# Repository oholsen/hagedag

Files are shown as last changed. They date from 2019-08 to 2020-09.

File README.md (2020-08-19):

# hagedag
DIY lawn mower robot

## Testing

Run unit tests:

    poetry run pytest -s

Run simulation:

    poetry run python .\record.py

(Replay log file, should add fail safe detection ++):

    poetry run python .\record.py .\data\burned-motor.log

## TODO

* motor burned (one wheel was tangled in grass):
  * wifi connection delayed - commands and feedback
  * figure out why robot estimate wrongly turned and why it did not recover when moving "right"
  * fix: move control to robot, detect connection delays, ignore delayed information, timestamp from STM32, use timestamp from GPS

* high load on motor detection - possibly integrate and average
  * cut in STM or in control? Control, as will get to know what is going on?
  * STM will stop robot if communication errors, safe to cut in control.
  * different max for instantaneous and average load?
  * Simply stop when above threshold (instantaneous)

* robot stuck detection: anomaly on prediction and GPS
  * measure distance travelled over last 5 say on GPS and compare to integrated speed

* wifi delay detection
    * shorter timeout (1s/2s)
    * embed timeout in command
    * alert in GUI

* stop cutter outside fence?
* cutter stuck detection
* revs sensor on cutter

* slow down near fence
* keep estimating position with odometer only when no GPS fix -> higher uncertainty

* Fence
    * increase area behind garage
    * reduce fence area near stairs

* App robustness
    * restart GPS service when USB unavailable, also ntrip client fails badly? restart service should be ok...
    * properly stop all tasks, also controld connection, from PC app
    * program firmware with heartbeat on commands

Usability:
    * Don't make PC app always be on top: run GUI task in own thread?
    * PC/Web/mobile app framework: pyplot, JS, plotly-dash, ...
    * identify what goes wrong / status
    * restart e.g. line scan from current position?

* Tidy up app:
   * remove unused code

* move app to robot

* change direction of robot

* slow down near fence, speed up in the middle (may make crash prediction below unnecessary - if reducing heartbeat timeout in robot)
* keep going for large HDOP if far from fence
* use GPS hdop in tracking, figure out why HDOP is 0.5 when RTK
* looser cut-off on no RTK - either adjust error in GPS tracking (check out HDOP in RMC)
 - or - accept no GPS for a while - at least if heading is good and is not going to crash.
 estimate time to impact from last good RTK position?
BUT: also quicker than 5s heartbeat timeout, i.e. direct STOP command if about to crash and loose RTK 
* avoid going in circles on drifting GPS: HDOP -> tracker could solve that
* area filling - scan lines
* if HDOP high: alternative targets or wait for ok HDOP
* fence bump control: reverse out from fence

* automatic charging
* docking garage
* camera
* camera coverage of garden
* realsense - mapping, collision avoidance

Mission control dashboard
- map (draw AOI, speeds/behavior, move fence, path, density, ..., GPS/tracking error, heading error)
- system health: show currents, battery level
- (E)stop button
- Duration, Ah drawn (total, trip (since charge), button for reset trip charge), distance covered
- Mode: fence bump, lines, manual, manual override (temporarily)
- Manual controls
- Start mission - which mission
- app to monitor status, with notifications on issues

Analytics
- GPS/tracking precision
- Coverage
- Replay/show mission on map

Mapping
- find fence - show position on map with manual control - recorder mode....

Mission control
- run to area of "little" probability
- speed and cut speed as fn(x,y)
- avoid tail swinging out (reverse back out, put GPS above cutter and turn around cutter)
- estimate error based on odometry and GPS signal - keep on going if looses RTK
- TODO: check GPS error when stopped and no RTK

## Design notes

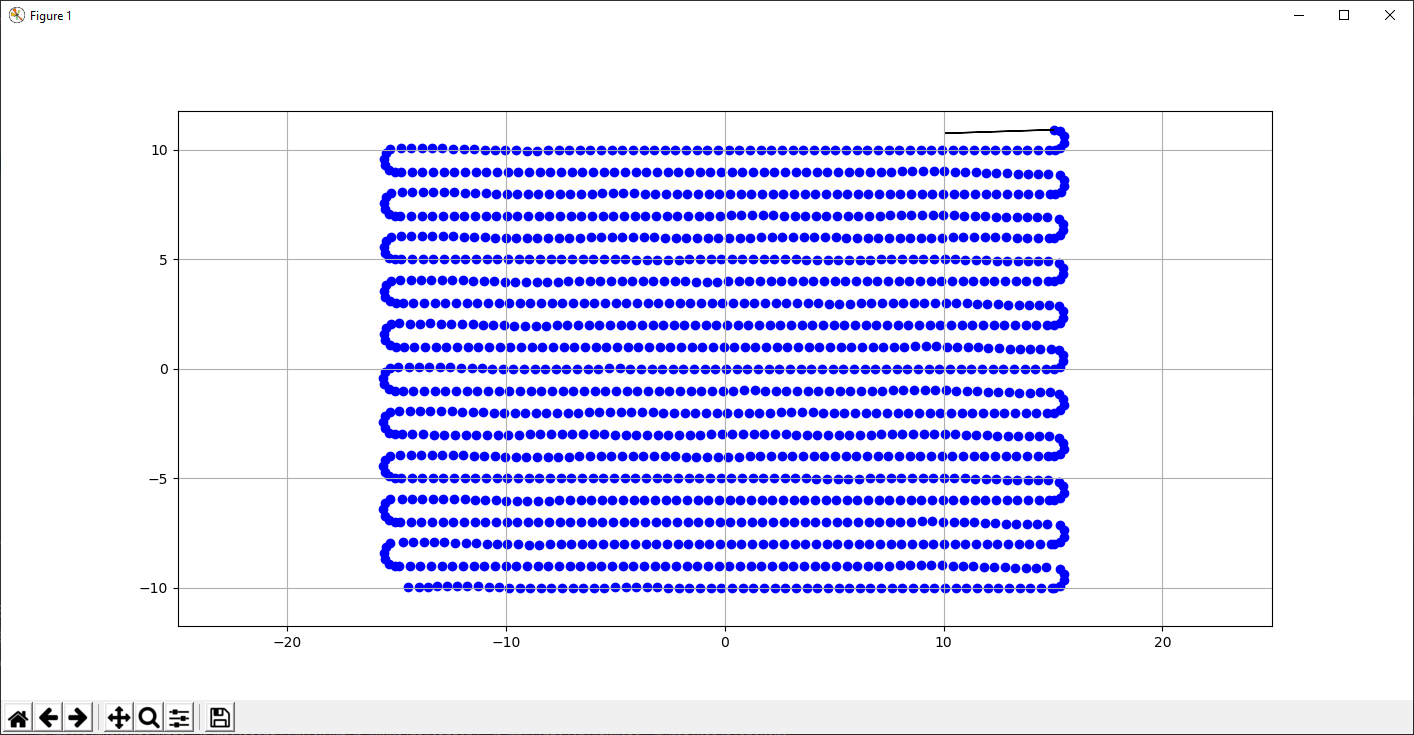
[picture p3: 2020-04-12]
control/simulation/fill_slip_pid.PNG

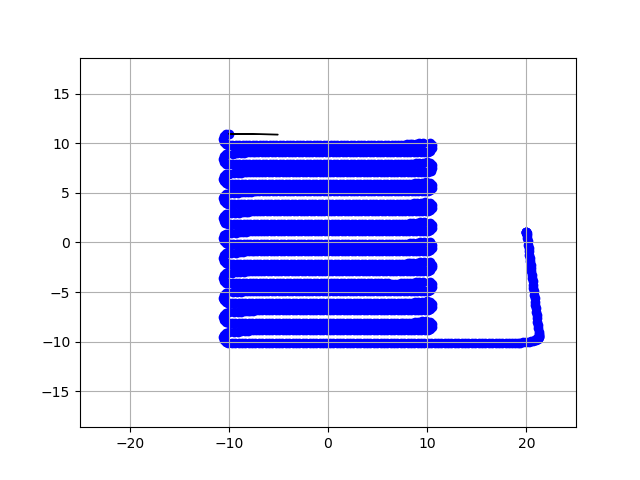
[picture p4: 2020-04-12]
control/simulation/fill_slip.png

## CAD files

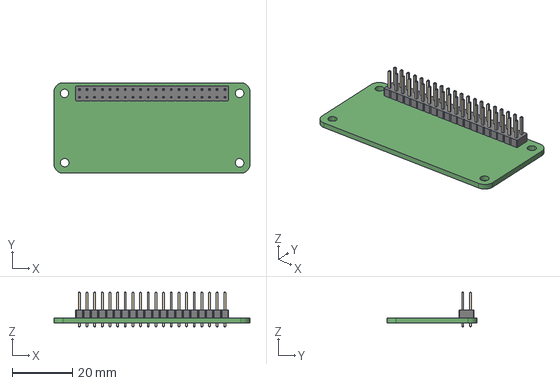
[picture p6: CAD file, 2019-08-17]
PCB/KiCad-Templates-master/3D Models/Raspberry Pi Zero W.step
65.0 x 30.0 x 11.5 mm

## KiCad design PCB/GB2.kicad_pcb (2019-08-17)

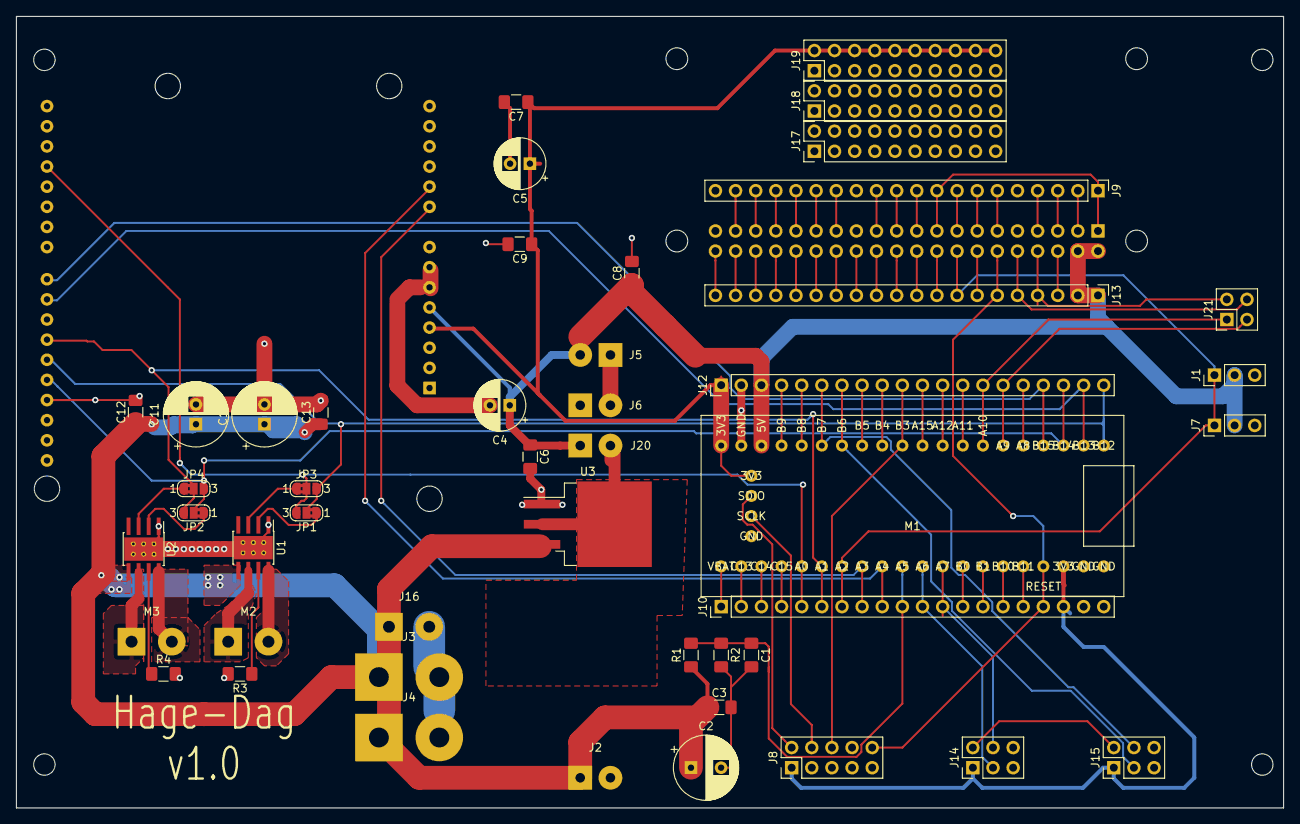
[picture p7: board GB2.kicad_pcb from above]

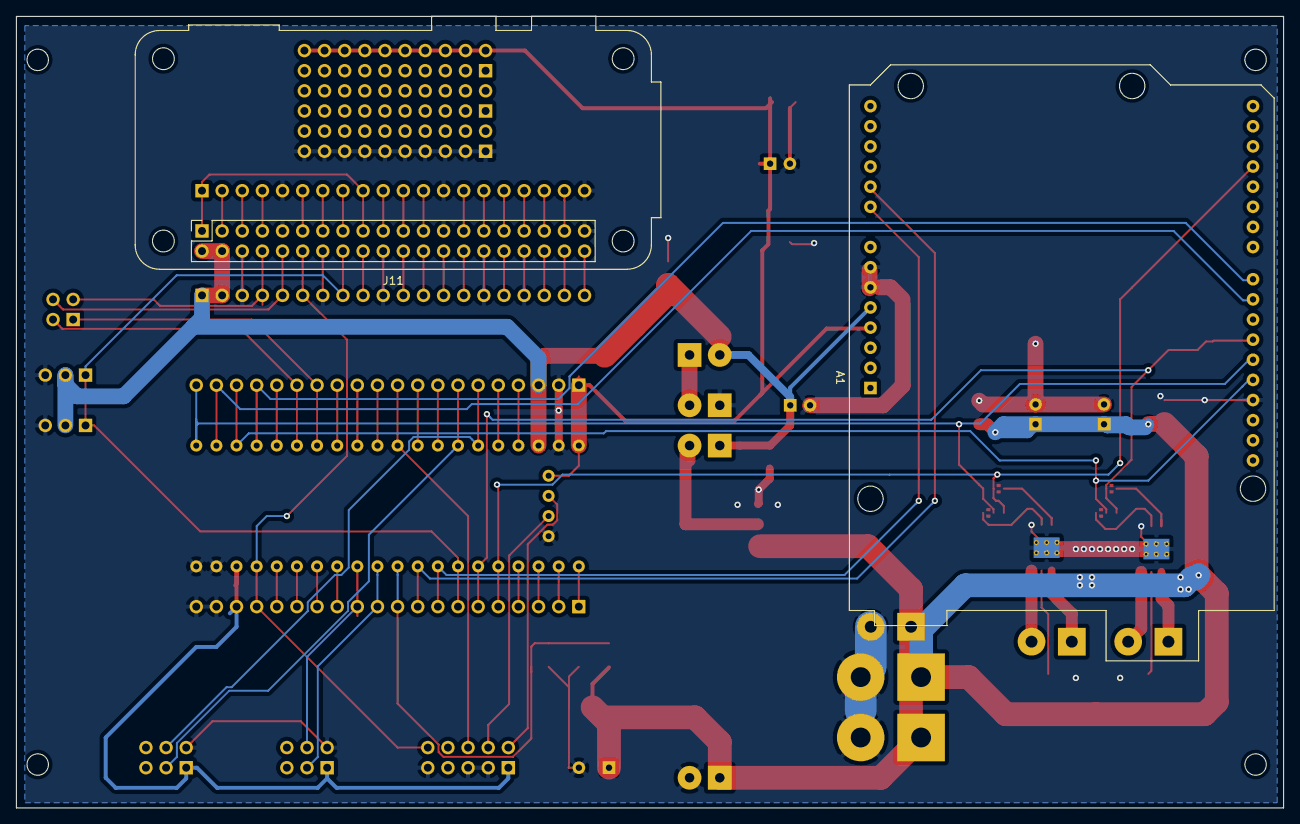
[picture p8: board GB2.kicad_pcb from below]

Board: 2 copper layers, 159.9 x 99.9 mm, 53 parts (2 on the bottom side), 79 nets.

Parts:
A1: Motor Shield; Arduino_UNO_R3_WithMountingHoles
C1, C3, C6, C7, C8, C9, C12, C13: C; C_1206_3216Metric_Pad1.42x1.75mm_HandSolder
C2: CP; CP_Radial_D8.0mm_P3.80mm
C4, C5: CP; CP_Radial_D6.3mm_P2.50mm
C10, C11: CP; CP_Radial_D8.0mm_P2.50mm
J1, J7: Cutter PWM; PinHeader_1x03_P2.54mm_Vertical
J2: BEC In; SolderWirePad_1x02_P3.81mm_Drill1.2mm
J3: Cutter; SolderWirePad_1x02_P7.62mm_Drill2.5mm
J4: Bat; SolderWirePad_1x02_P7.62mm_Drill2.5mm
J5: BEC; SolderWirePad_1x02_P3.81mm_Drill1.2mm
J6: BEC Out; SolderWirePad_1x02_P3.81mm_Drill1.2mm
J8: ARM; PinHeader_2x05_P2.54mm_Vertical
J9: RPi1; PinHeader_1x20_P2.54mm_Vertical
J10: STM2; PinHeader_1x20_P2.54mm_Vertical
J11: RPi; Raspberry_Pi_Zero_Socketed_THT_FaceDown_MountingHoles
J12: STM1; PinHeader_1x20_P2.54mm_Vertical
J13: RPi2; PinHeader_1x20_P2.54mm_Vertical
J14: Encoder A; PinHeader_2x03_P2.54mm_Vertical
J15: Encoder B; PinHeader_2x03_P2.54mm_Vertical
J16: Motors; SolderWirePad_1x02_P5.08mm_Drill1.5mm
J17, J18, J19: Proto; PinHeader_2x10_P2.54mm_Vertical
J20: VREG; SolderWirePad_1x02_P3.81mm_Drill1.2mm
J21: UART; PinHeader_2x02_P2.54mm_Vertical
JP1, JP2: IN2; SolderJumper-3_P1.3mm_Bridged2Bar12_RoundedPad1.0x1.5mm_Num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
JP3, JP4: IN1; SolderJumper-3_P1.3mm_Bridged2Bar12_RoundedPad1.0x1.5mm_Num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
M1: STM; STM-Nano
M2, M3: Motor_DC; SolderWirePad_1x02_P5.08mm_Drill1.5mm
MK1, MK2, MK3, MK4: Mounting_Hole_PAD; MountingHole_2.7mm
R1, R2, R3, R4: R; R_1206_3216Metric_Pad1.42x1.75mm_HandSolder
U1, U2: DRV8872DDA; Texas_HTSOP-8-1EP_3.9x4.9mm_P1.27mm_EP2.95x4.9mm_Mask2.4x3.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
U3: 5V; TO-263-3_TabPin2

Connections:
+3V3: A1.4, C5.1, C7.1, C9.1, J8.1, J10.18, J12.1, J14.1, J15.1, J19.2, J19.4, J19.6, J19.8, J19.10, J19.12, J19.14, J19.16, J19.18, J19.20, M1.1, M1.23, M1.44
+5V: A1.5, C4.1, C6.1, C8.1, J1.2, J5.2, J7.2, J11.2, J11.4, J12.3, J13.1, J13.2, J20.1, M1.3
+BATT: C2.1, C3.1, C10.1, C11.1, C12.1, C13.1, J2.1, J3.1, J4.1, J16.1, R1.1, U1.5, U2.5, U3.3
/BrakeA: A1.24, J12.19, M1.19
/BrakeB: A1.23, J12.17, M1.17
/EncA1: J10.11, J14.3, M1.30
/EncA2: J10.12, J14.4, M1.29
/EncB1: J12.7, J15.3, M1.7
/EncB2: J12.6, J15.4, M1.6
/PI_RX: J11.10, J13.5, J21.4
/PI_TX: J11.8, J13.4, J21.2
/PWMC: J1.1, J7.1, J10.7, J11.16, J13.8, M1.34
/Reset: J8.10, J10.17, J11.12, J13.6, M1.24
/STM_RX: J12.14, J21.1, M1.14
/STM_TX: J12.15, J21.3, M1.15
/SenseA: A1.9, J10.8, M1.33
/SenseB: A1.10, J10.9, M1.32
/VBAT_ADC: C1.1, J10.10, M1.31, R1.2, R2.1
/VREG: J20.2, U3.2
DIRA: A1.27, J12.20, JP1.2, JP3.3, M1.20
DIRB: A1.28, J12.18, JP2.2, JP4.3, M1.18
GND: A1.6, A1.7, A1.29, C1.2, C2.2, C3.2, C4.2, C5.2, C6.2, C7.2, C8.2, C9.2, C10.2, C11.2, C12.2, C13.2, J1.3, J2.2, J3.2, J4.2, J6.1, J7.3, J8.3, J8.5, J8.9, J9.5, J9.13, J9.20, J10.19, J10.20, J11.6, J11.9, J11.14, J11.20, J11.25, J11.30, J11.34, J11.39, J12.2, J13.3, J13.7, J13.10, J13.15, J13.17, J14.2, J15.2, J16.2, J17.1, J17.3, J17.5, J17.7, J17.9, J17.11, J17.13, J17.15, J17.17, J17.19, M1.2, M1.21, M1.22, M1.41, R2.2, R3.2, R4.2, U1.1, U1.9, U2.1, U2.9, U3.1
unnamed: J5.1, J6.2
unnamed: J8.2, M1.43
unnamed: J8.4, M1.42
unnamed: J10.1, M1.40
unnamed: J10.2, M1.39
unnamed: J10.3, M1.38
unnamed: J10.4, M1.37
unnamed: J10.13, M1.28
unnamed: J10.14, M1.27
unnamed: J10.15, M1.26
unnamed: J10.16, M1.25
unnamed: J9.1, J9.9, J11.1, J11.17
unnamed: J9.2, J11.3
unnamed: J9.3, J11.5
unnamed: J9.4, J11.7
unnamed: J9.6, J11.11
unnamed: J9.7, J11.13
unnamed: J9.8, J11.15
unnamed: J11.18, J13.9
unnamed: J9.10, J11.19
unnamed: J9.11, J11.21
unnamed: J11.22, J13.11
unnamed: J9.12, J11.23
unnamed: J11.24, J13.12
unnamed: J11.26, J13.13
unnamed: J9.14, J11.27
unnamed: J11.28, J13.14
unnamed: J9.15, J11.29
unnamed: J9.16, J11.31
unnamed: J11.32, J13.16
unnamed: J9.17, J11.33
unnamed: J9.18, J11.35
unnamed: J11.36, J13.18
unnamed: J9.19, J11.37
unnamed: J11.38, J13.19
unnamed: J11.40, J13.20
unnamed: J12.4, M1.4
unnamed: J12.5, M1.5
unnamed: J12.8, M1.8
unnamed: J12.9, M1.9
unnamed: J8.6, J12.10, M1.10
unnamed: J12.11, M1.11
unnamed: J12.12, M1.12
unnamed: J12.13, M1.13
unnamed: J12.16, M1.16
unnamed: JP1.1, U1.2
unnamed: JP2.1, U2.2
unnamed: JP3.1, U1.3
unnamed: JP4.1, U2.3
unnamed: M2.1, U1.6
unnamed: M2.2, U1.8
unnamed: M3.1, U2.6
unnamed: M3.2, U2.8
unnamed: R3.1, U1.7
unnamed: R4.1, U2.7
PWMA: A1.18, J10.5, JP1.3, JP3.2, M1.36
PWMB: A1.26, J10.6, JP2.3, JP4.2, M1.35

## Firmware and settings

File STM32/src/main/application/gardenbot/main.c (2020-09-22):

#include "board/board.h"
#include "board/led.h"
#include "hal/systick.h"
#include "hal/gpio.h"
#include "hal/delay.h"
#include "hal/adc.h"
#include "hal/pwm.h"
#include "hal/usart.h"
#include "hal/usart_rx.h"
#include "lib/motorcontrol.h"
#include "lib/pidcontrol.h"
#include <math.h>
#include <stdio.h>
#include <string.h>

#define M_PI        3.1415

// tick rate -> power
// 12k ticks per wheel rev
#define PID_Kp      1e-4
#define PID_Ti      0.2
#define PID_Td      1e-3
#define PID_alpha   0.1
#define PID_Imax    0.6


#define BATTERY_INTERVAL                20 // seconds


/*
TIM2 for motors, shared.
TIM3 and TIM4 for encoders.

TODO: current sense on analog input, 1.65V / A
2A max per channel, corresponding to 3.3V.

IA on A,3
IB on A,4

*/

#define MOTOR_PWM_TIMER         TIM2
#define MOTOR_PWM_FREQ          100e3
#define MOTOR_PWM_PERIOD        ((uint32_t) (SYSTEM_CLOCK / MOTOR_PWM_FREQ))

#define MAX_TICK_SPEED          5800
#define MOTOR_POWER_MAX         0.9
#define MOTOR_POWER_ALPHA       0.001 // approx 20s before overload triggers


// static uint32_t time; // seconds since boot
static float time; // seconds since boot
static char buf[128];
static int status;
#define STATUS_MAX_POWER    1


float set_speed_alpha = 5e-2;

// TODO: move to controller or motor
Pin_t sense_A = {GPIOA, 3};
Pin_t sense_B = {GPIOA, 4};


Pin_t usart1_tx = {GPIOA, 9};
Pin_t usart1_rx = {GPIOA, 10};

MotorControl_t motor_A = {
    .encoder = { .timer = TIM3, .ch1 = {GPIOA, 6}, .ch2 = {GPIOA, 7} },
    .motor = { .timer = MOTOR_PWM_TIMER, .channel = 1, .pwm = {GPIOA, 0}, .direction = {GPIOB, 12}, .brake = {GPIOB, 13} }
};

MotorControl_t motor_B = {
    .encoder = { .timer = TIM4, .ch1 = {GPIOB, 6}, .ch2 = {GPIOB, 7} },
    .motor = { .timer = MOTOR_PWM_TIMER, .channel = 2, .pwm = {GPIOA, 1}, .direction = {GPIOB, 14}, .brake = {GPIOB, 15} }
};

#define motor_R motor_A
#define motor_L motor_B
#define sense_R sense_A
#define sense_L sense_B


// Scheduler for motor control PID updates
Updater_t updater;
float cmd_timeout = 0.0f;  // time when command times out, 0 is timeout state
static float power_A, power_B;

Pin_t vbat_ain_pin = {GPIOA, 5};
Pin_t vbat_gnd_pin = {GPIOC, 15}; // Not used
uint32_t v_bat_scaled = 0;

#define V_BAT_ALPHA             5
// Calibration point: Vbat 12.53V Vin 3.046V ADC 3693
#define ADC_TO_V_BATC            (12.53f / 3693.0f)


static inline float battery_voltage(void)
{
    return (ADC_TO_V_BATC * v_bat_scaled) / (1 << V_BAT_ALPHA);
}


void battery_measure(void)
{
    uint16_t adc = adcf1_measure(vbat_ain_pin.bit);
    if (v_bat_scaled == 0) {
        v_bat_scaled = adc << V_BAT_ALPHA;
        return;
    }
    v_bat_scaled += adc - (v_bat_scaled >> V_BAT_ALPHA);
    // printf("BAT %d %d %.3f\n", adc, v_bat_scaled, battery_voltage());
}


void _reset(void) 
{
    status = 0;
    power_A = power_B = 0;
    motor_control_init(&motor_A, 0.0);
    motor_control_init(&motor_B, 0.0);
}


void _stop(void) 
{
    motor_control_set_speed(&motor_L, 0, 1);
    motor_control_set_speed(&motor_R, 0, 1);  
}

// command speeds are in ticks/s
// rotation is anti-clockwise from above
void _set_motor_speeds(float speed_L, float speed_R) {
    motor_control_set_speed(&motor_L, speed_L, set_speed_alpha);
    motor_control_set_speed(&motor_R, speed_R, set_speed_alpha);
} 


bool _check_command_timeout(void)
{
    if (cmd_timeout != 0.0f && time >= cmd_timeout) {
        snprintf(buf, sizeof(buf), "Timeout %.3f %.3f\n", time, cmd_timeout);
        usart_tx_string(USART1, buf);
        _stop();
        cmd_timeout = 0.0f;
        return false;
    }
    return true;
}


void _set_motion(float speed, float rotation, float timeout)
{
    cmd_timeout = timeout;
    float speed_L = speed - rotation;
    float speed_R = speed + rotation;
    if (_check_command_timeout())
    {
        _set_motor_speeds(speed_L, speed_R);
        snprintf(buf, sizeof(buf), "Ack %.3f m %.2f %.2f %.3f\n", time, speed, rotation, cmd_timeout);
        usart_tx_string(USART1, buf);
    }
}


void _handle_command(void)
{
  uint8_t line_buffer[256];
        
  //if (!usart_rx_input_pending(CONTROL_UART))
  if (!usart_rx_eol(CONTROL_UART))
    return;
  
  const char *line = (const char *) usart_rx_read_line(CONTROL_UART, line_buffer, sizeof(line_buffer), 0.5);
  if (line == NULL)
    return;
  
  printf("Control [%s]\n", line);
  snprintf(buf, sizeof(buf), "Control %s", line);
  usart_tx_string(USART1, buf);
        
  char name[16];
  float arg1, arg2, arg3, arg4, arg5;
  int n = sscanf(line, "%s %f %f %f %f %f", name, &arg1, &arg2, &arg3, &arg4, &arg5);
   
  if (n < 1)
    return;
  
  if (strcmp(name, ".") == 0) {
    _stop();
    return;
  }

  if (strcmp(name, "!") == 0) {
    _reset();
    return;
  }

  if (strcmp(name, "m") == 0 && n >= 4) {
    // arg1 is translation speed forwards in cm/s
    // arg2 is rotation speed in deg/s
    // arg3 is time at which the command times out
    _set_motion(arg1, arg2, arg3);
    return;
  }

  if (strcmp(name, "pid") == 0) {
    
    if (n >= 4) {
      float kp = arg1;
      float ti = arg2;
      float td = arg3;
      
      pidcontrol_config(&motor_L.pid, kp, ti, td, PID_alpha, -PID_Imax, +PID_Imax);
      motor_control_init(&motor_L, 0.0);
      pidcontrol_config(&motor_R.pid, kp, ti, td, PID_alpha, -PID_Imax, +PID_Imax);
      motor_control_init(&motor_R, 0.0);    
    }

    snprintf(buf, sizeof(buf), "PID %g %g %g\n", motor_L.pid.Kp, motor_L.pid.Ti, motor_L.pid.Td);
    usart_tx_string(USART1, buf);
    printf(buf);
    return;
  }
}


void _control_from_uart(void)
{

    printf("Control from UART\n");
    
    // motor timer
    RCC->APB1ENR |= RCC_APB1ENR_TIM2EN;

    // encoder timers
    RCC->APB1ENR |= RCC_APB1ENR_TIM3EN;
    RCC->APB1ENR |= RCC_APB1ENR_TIM4EN;
    
    // NOTE: current sensing should be synched with PWM!!!
    gpio_pin_mode(&sense_A, GPIO_ANALOG);
    gpio_pin_mode(&sense_B, GPIO_ANALOG);
    gpio_pin_mode(&vbat_ain_pin, GPIO_ANALOG);
    // gpio_pin_mode_f1(&vbat_ain_pin, GPIO_MODE_INPUT_ANALOG);
    
    adcf1_start();
    
    pwm_start(MOTOR_PWM_TIMER, MOTOR_PWM_PERIOD);
    
    pidcontrol_config(&motor_A.pid, PID_Kp, PID_Ti, PID_Td, PID_alpha, -PID_Imax, +PID_Imax);
    motor_control_init(&motor_A, 0.0);

    pidcontrol_config(&motor_B.pid, PID_Kp, PID_Ti, PID_Td, PID_alpha, -PID_Imax, +PID_Imax);
    motor_control_init(&motor_B, 0.0);
    
    // _test_power_speed();    

    uint32_t debugInterval = systick_seconds2ticks(1.0);
    uint32_t nextDebugTicks = systick_add(systick_read(), debugInterval);

    float nextBatteryTime = 0; // seconds
       
    updater_init(&updater);
    uint32_t updateInterval = systick_seconds2ticks(0.025);
    uint32_t nextUpdateTicks = systick_add(systick_read(), updateInterval);
    uint32_t updates = 0;
    
    uint32_t time_ticks = systick_read();    
    
    while (1)
    {

        _handle_command();
        
        uint32_t ticks = systick_read();
        if (systick_expired2(ticks, nextUpdateTicks)) {
            time += 0.025;
            nextUpdateTicks = systick_add(ticks, updateInterval);
            if ((status & STATUS_MAX_POWER) == 0) {
              if (fabs(power_A) < MOTOR_POWER_MAX && fabs(power_B) < MOTOR_POWER_MAX) {
                float dts = updater_update(&updater);
                motor_control_update(&motor_L, dts);
                motor_control_update(&motor_R, dts);
                power_A += MOTOR_POWER_ALPHA * (motor_A.pid.I - power_A);
                power_B += MOTOR_POWER_ALPHA * (motor_B.pid.I - power_B);
                updates++;
              }
              else {
                // Must reset motors to get going again
                printf("Power overload - stopping!\n");
                status |= STATUS_MAX_POWER;
                motor_set_power(&motor_A.motor, 0);
                motor_set_power(&motor_B.motor, 0);
              }
            }
        }
        
        ticks = systick_read();
        if (systick_expired2(ticks, time_ticks + SYSTICK_CLOCK)) {
            time_ticks = systick_add(time_ticks, SYSTICK_CLOCK);
            led_toggle();            
            battery_measure();
        }

        ticks = systick_read();
        if (systick_expired2(ticks, nextDebugTicks)) {
            /////////////////////////////////////////////////////
            // Debug
            /////////////////////////////////////////////////////

            nextDebugTicks = systick_add(ticks, debugInterval); // interval, skew when delayed
            //nextDebugTicks = systick_add(nextDebugTicks, debugInterval);  // periodic, can get serious backlog
                    
            printf("%.3f", time);
            //printf(" %d", updates);
            //printf(" %.3f", speed);
            printf(" %3d %3d", motor_A.encoder.sum, motor_B.encoder.sum);

            MotorControl_t *motor = &motor_A;
            float speed = motor->encoder.speed; // No need to low-pass filter
            printf(" %6.0f", speed);
            printf(" | %.3f | %.3f %.3f %.3f", motor->power, motor->pid.P, motor->pid.I, motor->pid.D);
#if 1
            // must be synched with PWM?? Or add LP filter on input...
            uint16_t current_L = adcf1_measure(sense_L.bit);
            uint16_t current_R = adcf1_measure(sense_R.bit);
            printf(" | %4d  %4d", current_L, current_R);
#endif       
            printf("\n");
            updates = 0;

            snprintf(buf, sizeof(buf), "Time %.3f\n", time);
            usart_tx_string(USART1, buf);

            // Distance travelled - in ticks
            snprintf(buf, sizeof(buf), "Ticks %d %d\n", motor_L.encoder.sum, motor_R.encoder.sum);
            usart_tx_string(USART1, buf);
            
            // Speed in revs/sec - could use cm/sec
            snprintf(buf, sizeof(buf), "Speed %.1f %.1f %.1f %.1f\n", motor_L.encoder.speed, motor_R.encoder.speed, motor_L.set_speed_lp, motor_R.set_speed_lp);
            usart_tx_string(USART1, buf);

            // snprintf(buf, sizeof(buf), "Power %6.3f %6.3f   %6.3f %6.3f\n", motor_L.power, motor_R.power, motor_L.pid.I, motor_R.pid.I);
            snprintf(buf, sizeof(buf), "Power %.3f %.3f\n", motor_L.power, motor_R.power);
            usart_tx_string(USART1, buf);

            snprintf(buf, sizeof(buf), "Status %d\n", status);
            usart_tx_string(USART1, buf);
        }

        _check_command_timeout();

        if (time >= nextBatteryTime) {
            nextBatteryTime = time + BATTERY_INTERVAL;
            float vbat = battery_voltage();
            snprintf(buf, sizeof(buf), "Battery %.3f\n", vbat);
            usart_tx_string(USART1, buf);
            printf(buf);
            // printf("BAT %d %.3f\n", v_bat_scaled, vbat);            
        }
        
    }    
}


// called from startup_stm32*.s
void SystemInit(void) {
}


static uint8_t usart_buffer[512];


// #include "tests.c"


int main(void)
{
    // TODO: use startup.s from CubeF1 LL in case want to manipulate interrupt vectors
    // TODO: could use HSE at 8MHz, can also use 72MHz!?

    // Use HSI at 8MHz x 8
    // Switch to 64MHz clock: 8MHz/2 * 16
    FLASH->ACR |= 2 * FLASH_ACR_LATENCY_0;
    RCC->CFGR = RCC_CFGR_PLLMULL16;
    RCC->CR |= RCC_CR_PLLON;
    while ((RCC->CR & RCC_CR_PLLRDY) == 0);
    RCC->CFGR |= RCC_CFGR_SW_PLL;
    while ((RCC->CFGR & RCC_CFGR_SWS) != RCC_CFGR_SWS_PLL);
    
    systick_start();
    
    // Enable the clock to GPIO ports
    RCC->APB2ENR |= RCC_APB2ENR_IOPAEN;
    RCC->APB2ENR |= RCC_APB2ENR_IOPBEN;
    RCC->APB2ENR |= RCC_APB2ENR_IOPCEN;


    led_init();
    led_on();

#if 0
    _test_led();
    _test_adc();
    _test_vbat();
    _test_motor();
    _test_pwm();
#endif
    
    //RCC->APB2ENR |= RCC_APB2ENR_USART1EN;
    usart_start(USART1, 115200);
    gpio_pin_mode(&usart1_tx, GPIO_MODE_OUTPUT_SPEED_HI | GPIO_MODE_OUTPUT_ALTERNATE);
    gpio_pin_mode(&usart1_rx, GPIO_MODE_INPUT | GPIO_MODE_INPUT_FLOATING);
    gpio_pin_pull_up(&usart1_rx);

#if 0
    for (;;) {
      while (!usart_rx_ready(USART1)); //        printf("S %2x ", USART1->SR);
      uint8_t ch = USART1->DR;
      printf("CH %x %c\n", ch, ch);
    }           
#endif
    
    usart_rx_start(USART1, usart_buffer, sizeof(usart_buffer));
    
    _control_from_uart();
   
#if 0
    while (1)
    {
        uint8_t line_buffer[256];
        
        char *line = (char *) usart_rx_read_line(USART1, line_buffer, sizeof(line_buffer), 3.0);

        led_on();
        delay_ms(500);
        
        led_off();
        delay_ms(500);
        
        printf("Received: %s\n", line);
        usart_tx_string(USART1, "Hello from STM!\n");
    }
#endif
}

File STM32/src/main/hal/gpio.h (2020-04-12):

#pragma once

#include <assert.h>

typedef struct {
    GPIO_TypeDef *port;
    unsigned int bit;
} Pin_t;



// 4 bits 2xCNF + 2xMODE per pin
// Reset state 0100, i.e. input floating
/*
Mode
0       Input
1       Output, med speed, max 10MHz
2       Output, low speed, max 2MHz
3       Output, hi speed, max 50MHz

CNF (Input)
0       Analog
1       Floating input (reset state)
2       Input with pull up/down
3       Reserved

// option to disable pull? pull is weak?
PxODR for CNF=2:
0       Pull-down
1       Pull-up

CNF (Output)
CNF1    
0       Push-pull
1       Open-drain
CNF0
0       General purpose output
1       Alternate function output

*/


// Need one of these followed by INPUT/OUTPUT specific settings
#define GPIO_MODE_INPUT              0
#define GPIO_MODE_OUTPUT_SPEED_MED   1
#define GPIO_MODE_OUTPUT_SPEED_LOW   2
#define GPIO_MODE_OUTPUT_SPEED_HI    3


// Direct mode to gpio_mode()
#define GPIO_MODE_INPUT_ANALOG               (0 << 2)
#define GPIO_MODE_INPUT_FLOATING             (1 << 2)
#define GPIO_MODE_INPUT_PULL_UP_DOWN         (2 << 2)

#define GPIO_MODE_OUTPUT_PUSH_PULL           (0 << 2)
#define GPIO_MODE_OUTPUT_OPEN_DRAIN          (1 << 2)
#define GPIO_MODE_OUTPUT_GENERAL             (0 << 3)
#define GPIO_MODE_OUTPUT_ALTERNATE           (1 << 3)

// Generic digital output
#define GPIO_OUTPUT	(GPIO_MODE_OUTPUT_PUSH_PULL | GPIO_MODE_OUTPUT_GENERAL | GPIO_MODE_OUTPUT_SPEED_HI)
#define GPIO_ANALOG     (GPIO_MODE_INPUT | GPIO_MODE_INPUT_ANALOG)



static inline void _gpio_pin_mode(GPIO_TypeDef *port, uint32_t pin, uint32_t mode) {
    assert(pin < 16);
    assert(mode < 16);
    __IO uint32_t *reg = &port->CRL;
    if (pin >= 8) {
        reg = &port->CRH;
        pin -= 8;
    }
    assert(pin < 8);
    uint32_t mask = 0xf << (4 * pin);
    *reg = ((*reg) & (~mask)) | (mode << (4 * pin));
}


static inline void gpio_pin_mode(Pin_t *pin, uint32_t mode) {
    _gpio_pin_mode(pin->port, pin->bit, mode);
}

static inline void gpio_pin_set(Pin_t *pin) {
    pin->port->BSRR = 1 << pin->bit;
}

static inline void gpio_pin_clr(Pin_t *pin) {
    pin->port->BRR = 1 << pin->bit;
}

static inline void gpio_pin_toggle(Pin_t *pin) {
    pin->port->ODR ^= 1 << pin->bit;
}

static inline void gpio_pin_assign(Pin_t *pin, bool value) {
    pin->port->BSRR = 1 << (value ? pin->bit : pin->bit + 16);
}

static inline void gpio_pull_down(GPIO_TypeDef *port, uint32_t pin) {
  port->BSRR = 1 << (pin + 16); // Clear bit in ODR
}

static inline void gpio_pull_up(GPIO_TypeDef *port, uint32_t pin) {
  port->BSRR = 1 << pin; // Set bit in ODR
}

static inline void gpio_pin_pull_up(Pin_t *pin) {
  pin->port->BSRR = 1 << pin->bit; // Set bit in ODR
}

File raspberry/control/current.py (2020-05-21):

#!/usr/bin/env python
import time
import INA3221

ina3221 = INA3221.INA3221(addr=0x40)

# ch1: cutter
# ch2: wheels
# ch3: 5V BEC RPi and uC

def measure():
    # same bus voltage for all channels
    bus_voltage = ina3221.getBusVoltage_V(1)
    shunt_mV = ina3221.getShuntVoltage_mV(1)
    battery_voltage = bus_voltage + 0.001 * shunt_mV

    # current in amps
    i1 = 0.001 * ina3221.getCurrent_mA(1) 
    i2 = 0.001 * ina3221.getCurrent_mA(2)
    i3 = 0.001 * ina3221.getCurrent_mA(3)

    return i1, i2, i3, battery_voltage



def main2():
    while True:
        i1, i2, i3, v_bat = measure()
        print(f"{v_bat:3.2f} V  {i1:3.2f} mA  {i2:3.2f} mA  {i3:3.2f} mA")
        time.sleep(1.0)


def main():
    while True:
        print("------------------------------")
        for channel in range(1, 4):
            busvoltage = ina3221.getBusVoltage_V(channel)
            shuntvoltage = ina3221.getShuntVoltage_mV(channel)
            current_mA = ina3221.getCurrent_mA(channel)  
            loadvoltage = busvoltage + (shuntvoltage / 1000)    
            print(f"{channel}   {busvoltage:3.2f} V   {loadvoltage:3.2f} V  {shuntvoltage:3.2f} mV {current_mA:3.2f} mA")        
        print()
        # print(ina3221.read())
        # print()

        time.sleep(1.0)


if __name__ == "__main__":
    main2()

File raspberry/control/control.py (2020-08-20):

import serial_asyncio
import pigpio
import servo
import signal
import logging
import asyncio

logger = logging.getLogger("controld.control")


pi = pigpio.pi()
pi.set_mode(14, pigpio.ALT5)  # TXD
pi.set_mode(15, pigpio.ALT5)  # RXD

from cutter import cutter



def reset_timeout():
    signal.alarm(5)  # seconds


def timeout(writer):
    logger.info('Cutter timeout')
    cutter.stop()
    # stop(writer)


async def open():

    # https://tinkering.xyz/async-serial/
    reader, writer = await serial_asyncio.open_serial_connection(url="/dev/ttyS0", baudrate=115200, timeout=3.0)

    loop = asyncio.get_event_loop()
    # loop.add_signal_handler(signal.SIGALRM, lambda: asyncio.ensure_future(timeout(writer)))
    loop.add_signal_handler(signal.SIGALRM, lambda: timeout(writer))

    # Arm the motor controller by giving PWM signal. 
    # For both reversible and non-reversible motors:
    cutter.stop()

    return reader, writer


def send(writer, msg):
    msg = msg + '\n'
    writer.write(msg.encode('ascii'))
    

def stop(writer):
    send(writer, '.')


def handle(writer, data):
    # Dispatch message to RPI or STM
    assert data == data.strip()
    logger.debug("handle %r", data)

    if data == 'STOP':
        stop(writer)
        return

    if data.startswith('CUT'):
        try:
            cols = data.split()
            power = float(cols[1])
            cutter.power(power)
            reset_timeout()
        except:
            cutter.off()
            logger.error("Failed to handle CUT: %r", data, exc_info=1)
        return

    # Forward commands below to STM but intercept for local processing

    if data == '!':
        cutter.off()
    elif data == '.':
        pass
        # cutter.off()

    send(writer, data)

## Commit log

2019-08-17 Working prototype of keeping the robot in a box
2019-08-17 RPi code: dead ugly web GUI and control via web socket
2019-08-17 Add PCB project for KiCad
    [GB2-B_Cu.gbl, GB2-B_Mask.gbs, GB2-B_SilkS.gbo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]
2019-08-17 Filter blob area
2019-08-18 Use config file, color dump on mouse click in "frame"
2019-09-07 Add Cut0 button, also stop STM on RPi heartbeat timeout
2019-09-07 Fix battery and heartbeat
2019-09-14 Motion tracking and optical flow tests
2019-09-15 Filter commands with robot.control config
2019-09-15 Factor out old processing and use diff.process2()
    Create ROI from fence before first frame
2019-09-15 Remove unused code
    Handle events also on frames without position
2019-09-23 remove debug print
2020-03-07 Add PID control
2020-04-12 Add firmware for STM32 controller
2020-05-03 Use brushed motor cutter
2020-05-04 Working horizontal line control
    Roughly +-10 cm vertical error
    [control.py, controld.py]
2020-05-16 Use brushless cutter motor again. Stop command does not stop cutter.
2020-05-16 WIP: current measurement
2020-05-16 Output Revs in correct order
    [main.c]
2020-05-21 Measure currents
2020-05-22 Working naiive fence bump control
    - filter on RTK fix
2020-05-31 Mission config, HDOP filter, filter GPS msgs, battery cut-off
2020-05-31 Graceful degradation on current measurement failure
    [controld.py]
2020-06-08 Send single error message on current measurement
    [controld.py]
2020-06-16 Add LineControl, reduce speed near target, tighter track control
    [control.py]
2020-06-18 Keep battery low condition
    Avoids draining battery very low on numerous restarts - should measure battery low when motors run.
2020-06-26 Web GUI prototype
2020-07-05 WIP: "m" command with timeout, report STM32 time
2020-07-05 Record STM32 time
2020-07-18 Bump lodash from 4.17.15 to 4.17.19 in /raspberry/gui
    Bumps [lodash](https://github.com/lodash/lodash) from 4.17.15 to 4.17.19.
    - [Release notes](https://github.com/lodash/lodash/releases)
    - [Commits](https://github.com/lodash/lodash/compare/4.17.15...4.17.19)
2020-07-22 WIP: power high fail safe
2020-08-04 Fixes for ScanHLine control
    [control.py]
2020-08-08 Motor control by ticks/s
2020-08-08 Fix omega on arc in ScanHLine
    [control.py]
2020-08-20 Remove spaces in Power message
2020-08-20 Add Status and Power and cut heartbeat
2020-08-20 Set 5s timeout on CUT command
2020-08-20 Fixes for new protocol, use Status message to detect overload
    [control.py]
2020-08-26 Cleanup and doc, include some thinking around holes
2020-09-02 Bump bl from 4.0.2 to 4.0.3 in /raspberry/gps
    Bumps [bl](https://github.com/rvagg/bl) from 4.0.2 to 4.0.3.
    - [Release notes](https://github.com/rvagg/bl/releases)
    - [Commits](https://github.com/rvagg/bl/compare/v4.0.2...v4.0.3)
2020-09-22 Raise threshold and integration time for power overload

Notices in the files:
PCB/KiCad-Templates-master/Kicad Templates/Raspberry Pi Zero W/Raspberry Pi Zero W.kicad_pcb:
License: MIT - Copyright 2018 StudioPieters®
